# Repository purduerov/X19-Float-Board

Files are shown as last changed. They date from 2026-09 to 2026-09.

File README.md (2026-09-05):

# X19 Float Board

The Float Board manages buoyancy systems, motor drivers, sensor telemetry, and power distribution for the Purdue ROV X19 vehicle.

---

## 🚀 Quickstart: Opening the Project (Recommended)

**Always open the project using the 1-click launcher:**

* **Windows:** Double-click `LAUNCH_KICAD.bat`
* **macOS / Linux:** Run `./LAUNCH_KICAD.sh`

### What the Launcher Does Automatically:
1. ⚙️ **Configures Git Hooks & Clean Filters:** Sets up Git to strip volatile viewport/zoom coordinates on every commit, preventing merge conflicts.
2. 🔄 **Auto-Updates Component Library:** Pulls the freshest symbols, footprints, and 3D models from `purdue-rov-kicad-lib` before opening.
3. 📐 **Opens KiCad:** Launches `X19-Float-Board.kicad_pro` with all 6 central library categories pre-linked.

---

## Cloning the Repository
Clone recursively to ensure the central component library is initialized:
```bash
git clone --recursive https://github.com/purduerov/X19-Float-Board.git
cd X19-Float-Board
```

## Central Component Library & Manager GUI

The project links to the central `purdue-rov-kicad-lib` submodule mapped across 6 categories in `sym-lib-table` and `fp-lib-table`:
- `rov_passives`: Resistors, capacitors, inductors, crystals
- `rov_power`: Voltage regulators, buck/boost converters, MOSFETs, diodes
- `rov_logic`: MCUs, logic ICs, op-amps, drivers, level shifters
- `rov_connectors`: Power terminals, XT60, headers, USB, JST connectors
- `rov_sensors`: IMUs, temperature, pressure sensors
- `rov_mech`: Mounting holes, standoffs, test points

### Launching the Library Manager GUI
To browse parts, inspect footprints, edit properties, or add/delete components in the shared library:
- **Windows:** Double-click `libs\purdue-rov-kicad-lib\LIBRARY_MANAGER.bat`
- **macOS / Linux:** Run `./libs/purdue-rov-kicad-lib/LIBRARY_MANAGER.sh`

## Schematic Hierarchy

The schematic is organized across functional sub-sheets:
- `X19-Float-Board.kicad_sch`: Root top-level sheet.
- `pwr.kicad_sch`: Power regulation and distribution.
- `stm32.kicad_sch`: Main microcontroller circuit and programming interface.
- `Motor.kicad_sch`: Motor driver stages and control signals.
- `sensor.kicad_sch`: Environmental and diagnostic sensor telemetry.
- `rf.kicad_sch`: Wireless/radio transceiver circuitry.
- `switch.kicad_sch`: Power switching logic.

## Design Rules & Clearances

- High-voltage / high-current motor traces maintain isolation rules configured in `custom_rules.kicad_dru`.
- All symbols must adhere to central library guidelines.

## Automated CI/CD & DevOps Preflight Checks

All CI/CD automation and tooling are centralized in [`purduerov/pcb-devops`](https://github.com/purduerov/pcb-devops):
1. **Automated Git Clean Filters:** Configured automatically by `.githooks/pre-commit` to prevent viewport/zoom merge noise.
2. **KiCad Symbol Linting:** Validates mandatory fields (`MPN`, `Manufacturer`, `Category`, `DigiKey`, `Datasheet`, `Temp_Range`) on all library components.
3. **ERC & DRC Validation:** Executes Electrical and Design Rules Checks via KiBot in GitHub Actions.
4. **Artifact Generation:** Automatically exports Schematic PDFs, Board Layout PDFs, and Interactive HTML BOMs on every pull request.

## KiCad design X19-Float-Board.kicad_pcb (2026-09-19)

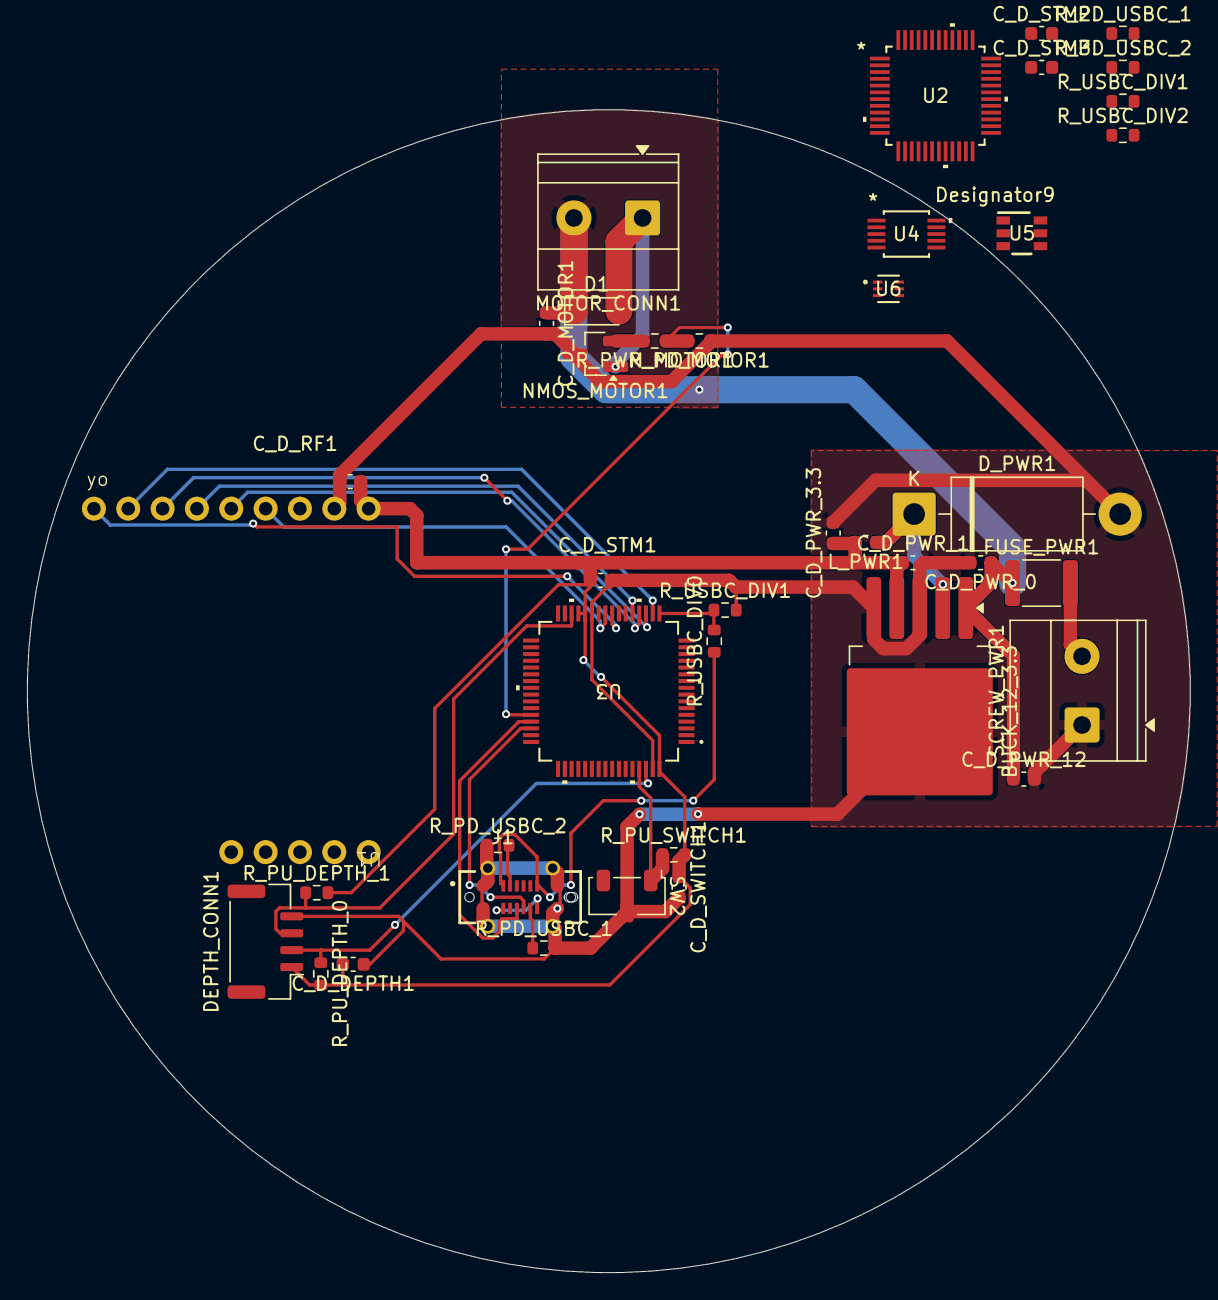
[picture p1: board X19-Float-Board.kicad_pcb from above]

Board: 2 copper layers, 86.0 x 86.0 mm, 41 parts (0 on the bottom side), 26 nets.

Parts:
BUCK_12_3.3: LM2596S-3.3; TO-263-5_TabPin3
C_D_DEPTH1: 100nF; C_0603_1608Metric
C_D_MOTOR1: 100nF; C_0603_1608Metric
C_D_PWR_0: 680µF; C_0603_1608Metric
C_D_PWR_1: 220µF; C_0603_1608Metric
C_D_PWR_3.3, C_D_PWR_12: 4.7µF; C_0603_1608Metric
C_D_RF1: 100nF; C_0603_1608Metric
C_D_STM1, C_D_STM2, C_D_STM3: 100nF; C_0603_1608Metric
C_D_SWITCH1: 100nF; C_0603_1608Metric
D1: D_MOTOR; D_SOD-123
DEPTH_CONN1: Conn_01x04_Pin; JST_GH_BM04B-GHS-TBT_1x04-1MP_P1.25mm_Vertical
D_PWR1: 1N5822; D_DO-201AD_P15.24mm_Horizontal
FUSE_PWR1: 2A 12V PTC fuse; Fuse_1812_4532Metric
J1: USB4220-03-1040-C_REVA; GCT_USB4220-03-1040-C_REVA
L_PWR1: 33µH; L_0603_1608Metric
MOTOR_CONN1: Motor; TerminalBlock_Phoenix_MKDS-1,5-2-5.08_1x02_P5.08mm_Horizont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
NMOS_MOTOR1: NMOS; SOT-23_Handsoldering
R_PD_MOTOR1: 10kΩ; R_0603_1608Metric
R_PD_USBC_1, R_PD_USBC_1#2: 5.1k; R_0603_1608Metric
R_PD_USBC_2, R_PD_USBC_2#2: 5.1kΩ; R_0603_1608Metric
R_PU_DEPTH_0, R_PU_DEPTH_1: 4.7kΩ; R_0603_1608Metric
R_PU_SWITCH1: 10kΩ; R_0603_1608Metric
R_PWM_MOTOR1: 220Ω; R_0603_1608Metric
R_USBC_DIV0, R_USBC_DIV1: 20kΩ; R_0603_1608Metric
R_USBC_DIV1#2, R_USBC_DIV2: 10kΩ; R_0603_1608Metric
SCREW_PWR1: Screw_Terminal_01x02; TerminalBlock_Phoenix_MKDS-1,5-2-5.08_1x02_P5.08mm_Horizont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
SW2: SW_Nidec_CAS-120A1; Nidec_Copal_CAS-120A
U1: rf module
U2: STM32C542CCT6; LQFP48-7X7
U3: STM32G431RBT6; LQFP64-10x10mm
U4: INA228AIDGSR; VSSOP10_DGS_TEX
U5: TPS561208DDCR; DDC0006A_N
U6: TMP1075NDRLR; SOT5X3-6_DRL_TEX

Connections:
3.3 V: BUCK_12_3.3.4 (FB), C_D_DEPTH1.2, C_D_PWR_1.1, C_D_PWR_3.3.1, C_D_RF1.2, C_D_STM1.1, C_D_STM2.2, C_D_STM3.1, C_D_SWITCH1.1, DEPTH_CONN1.1, L_PWR1.2, R_PU_DEPTH_0.2, R_PU_DEPTH_1.2, R_PU_SWITCH1.2, U1.6 (VIN), U2.9 (VREF+), U2.24 (VDD), U2.48 (VDD), U3.28 (VREF+), U3.29 (VDDA), U3.64 (VDD), U4.6 (VS), U6.5 (V+)
12 V: BUCK_12_3.3.1 (VIN), C_D_MOTOR1.1, C_D_PWR_0.1, C_D_PWR_12.1, D1.1 (K), FUSE_PWR1.1, MOTOR_CONN1.2, U5.3 (VIN)
/Motor/Motor PWM: R_PD_MOTOR1.2, R_PWM_MOTOR1.1, U2.19 (PB1), U3.44 (PA10)
/Sensors/Depth SCL: DEPTH_CONN1.2, R_PU_DEPTH_0.1, U2.39 (PB3)
/Sensors/Depth SDA: DEPTH_CONN1.3, R_PU_DEPTH_1.1, U2.40 (PB4)
/Switch/switch: R_PU_SWITCH1.1, SW2.1 (C), U2.38 (PA15), U3.61 (PB8-BOOT0)
/USB-C/USB-C_VBUS_A: R_USBC_DIV1.2, R_USBC_DIV2.1
/rf/RF INT: U1.9 (G0), U2.18 (PB0), U3.25 (PB1)
/rf/RF MISO: U1.11 (MISO), U2.16 (PA6), U3.21 (PA7)
/rf/RF MOSI: U1.12 (MOSI), U2.15 (PA5), U3.20 (PA6)
/rf/RF NSS: U1.13 (CS), U2.13 (PA3), U3.18 (PA4)
/rf/RF RST: U1.14 (RST), U2.17 (PA7), U3.24 (PB0)
/rf/RF SCK: U1.10 (SCK), U2.14 (PA4), U3.19 (PA5)
GND: BUCK_12_3.3.3 (GND), BUCK_12_3.3.5 (~ON/OFF), C_D_DEPTH1.1, C_D_MOTOR1.2, C_D_PWR_0.2, C_D_PWR_1.2, C_D_PWR_3.3.2, C_D_PWR_12.2, C_D_RF1.1, C_D_STM1.2, C_D_STM2.1, C_D_STM3.2, C_D_SWITCH1.2, DEPTH_CONN1.4, D_PWR1.2 (A), J1.A1 (GND_A), J1.A12 (GND_A), J1.B1 (GND_B), J1.B12 (GND_A), J1.S1 (SHIELD), J1.S2 (SHIELD), J1.S3 (SHIELD), J1.S4 (SHIELD), NMOS_MOTOR1.3 (S), R_PD_MOTOR1.1, R_PD_USBC_1.2, R_PD_USBC_1#2.2, R_PD_USBC_2.1, R_PD_USBC_2#2.1, R_USBC_DIV1#2.2, R_USBC_DIV2.2, SCREW_PWR1.1, SW2.2 (B), U1.7 (GND), U2.23 (VSS), U2.47 (VSS), U3.27 (VSSA), U3.63 (VSS), U4.1 (A1), U4.2 (A0), U4.7 (GND), U5.1 (GND), U6.2 (GND), U6.4 (A0)
unnamed: BUCK_12_3.3.2 (OUT), D_PWR1.1 (K), L_PWR1.1
unnamed: D1.2 (A), MOTOR_CONN1.1, NMOS_MOTOR1.1 (D)
unnamed: J1.A5 (CC1), R_PD_USBC_2.2, R_PD_USBC_2#2.2
unnamed: J1.B5 (CC2), R_PD_USBC_1.1, R_PD_USBC_1#2.1
unnamed: J1.B7 (DN2), U3.45 (PA11)
unnamed: J1.B6 (DP2), U3.46 (PA12)
unnamed: NMOS_MOTOR1.2 (G), R_PWM_MOTOR1.2
unnamed: FUSE_PWR1.2, SCREW_PWR1.2
unnamed: R_USBC_DIV0.2, R_USBC_DIV1#2.1, U3.17 (PA3)
unnamed: U4.8 (VBUS), U4.10 (IN+)
VBUS_A: J1.A4 (VBUS_A), J1.A9 (VBUS_A), R_USBC_DIV0.1, R_USBC_DIV1.1
VBUS_B: J1.B4 (VBUS_B), J1.B9 (VBUS_B)

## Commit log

2026-07-24 chore: initialize project name to X19-Float-Board and cleanup template config
    [X19-Float-Board.kicad_pcb, X19-Float-Board.kicad_sch]
2026-07-24 Draft of Schematic
    I just pasted in my old draft so it's on the repository
    [X19-Float-Board.kicad_sch]
2026-07-27 Added hierarchical sheets
    Added the sheets and how I'm splitting up the components, may have used too many, I'm not sure how to use these. Will update components and wiring soon
    [Motor.kicad_sch, X19-Float-Board.kicad_sch, rf.kicad_sch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]
2026-07-28 Overhaul
    Overhauled the schematic so all the components are correct, rewired power to be 12 V instead of 9 V and connected hierarchical labels between modules. Added more decoupling capacitors where they were missing.
    [Motor.kicad_sch, X19-Float-Board.kicad_sch, pwr.kicad_sch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]
2026-07-28 Clean up
    Minor fixes to mistakes in the schematic
    [Motor.kicad_sch, pwr.kicad_sch, rf.kicad_sch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]
2026-07-29 started layout
    in meeting
    [X19-Float-Board.kicad_pcb, sensor.kicad_sch, untitled.kicad_sch]
2026-08-12 Footprint
    Found footprints for multiple components and imported them to be used in PCB
    [X19-Float-Board.kicad_pcb, rfimp.kicad_pcb, rfimp.kicad_sch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]
2026-08-12 Gave footprints to everything
    Footprints
    [Motor.kicad_sch, X19-Float-Board.kicad_sch, pwr.kicad_sch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]
2026-08-13 Custom RF module and component
    Created my own setup for the footprint for the custom RF module
    [X19-Float-Board.kicad_pcb, rf.kicad_sch]
2026-08-13 Corrected stm32 symbol
    made corrections to the stm32 for the package and the schmeatic
    [X19-Float-Board.kicad_pcb, stm32.kicad_sch]
2026-08-14 ci(devops): setup centralized hardware CI/CD pipeline and PDF autogeneration for schematic and layout
2026-08-19 Modifications to power system to support what is required
    modified
    [X19-Float-Board.kicad_pcb, X19-Float-Board.kicad_sch, pwr.kicad_sch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]
2026-08-19 Completed routing of PCB
    Placed all components and routed pcb, large amount of drc errors, unsure
    [X19-Float-Board.kicad_pcb]
2026-08-19 Finalized Traces
    Potentially finallized traces
    [X19-Float-Board.kicad_pcb]
2026-08-19 Schematic updates
    Schematic updates to match with pcb edits
    [pwr.kicad_sch]
2026-08-27 docs: rewrite README with board-specific documentation and update submodule
2026-08-27 chore(submodule): update purdue-rov-kicad-lib to latest master
2026-09-01 refactor: organize scripts into scripts/ directory and configure 6-category library tables and launchers
    [untitled.kicad_sch]
2026-09-01 refactor: eliminate local scripts and centralize all automation in pcb-devops
2026-09-01 chore(ci): update pinned pcb-devops SHA and reflect PDF/BOM outputs in docs
2026-09-01 feat(ci): enable automated GitHub Pages portal and live interactive BOM deployment
2026-09-01 ci: point reusable workflow to pcb-devops@master for zero-maintenance CI propagation
2026-09-01 feat: auto-pull latest board commits with autostash on project launch
2026-09-02 refactor(launcher): proxy root LAUNCH_KICAD scripts directly to central pcb-devops master
2026-09-02 USB-C + Complete wiring
    Compltetly wired the pcb (I don't understand the DRC errors) and added a usb C to flash the stm, modified the switch to be the BOOT0 for the stm so it controls whether the stm is in flash mode
    [Motor.kicad_sch, X19-Float-Board.kicad_pcb, X19-Float-Board.kicad_sch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]
2026-09-05 Checkpoint
    Checkpoint, pre battery telemetry, pre new stm
    [Motor.kicad_sch, X19-Float-Board.kicad_pcb, sensor.kicad_sch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]
2026-09-05 Library Reforms
    moved libraries around
    [rfimp.kicad_pcb, rfimp.kicad_sch]
2026-09-05 Updated components from x19 BOM
    components
2026-09-09 chore: remove tracked backup file X19-Float-Board-eagle-import.bak
2026-09-09 chore(submodule): ensure purdue-rov-kicad-lib points to latest master
2026-09-09 chore(submodule): sync purdue-rov-kicad-lib to 3b036a0
2026-09-09 chore(submodule): sync purdue-rov-kicad-lib to b8f2bd1
2026-09-09 chore(infra): sync goated KiCad launcher, library tables, and purdue-rov-kicad-lib
2026-09-10 chore(githooks): harden submodule sync and update purdue-rov-kicad-lib
2026-09-10 chore(submodule): update purdue-rov-kicad-lib to d63fa5e
2026-09-10 chore(infra): sync latest infrastructure tooling from board-template
2026-09-10 chore(submodule): sync purdue-rov-kicad-lib to latest master
2026-09-19 Update
    Update
    [TELEM.kicad_sch, USB-C.kicad_sch, X19-Float-Board.kicad_pcb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]
2026-09-19 chore(submodule): fast-forward purdue-rov-kicad-lib to latest master
2026-09-19 Small changes to hierarchy
    Small Changes
    [X19-Float-Board.kicad_sch]
2026-09-19 todolist update
    update of the to do list on schematic
    [USB-C.kicad_sch, X19-Float-Board.kicad_pcb, X19-Float-Board.kicad_sch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]
2026-09-19 chore(submodule): bump purdue-rov-kicad-lib to latest master
2026-09-19 ci: set strict_drc to false to generate PDFs and artifacts for WIP boards
2026-09-21 Updated Schematic
    Updated parts of todo list for schematic
    [TELEM.kicad_sch, X19-Float-Board.kicad_sch, pwr.kicad_sch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]
2026-09-22 Updated Schematic
    Updated schematic
    Cleaned up dense portions
    added H bridge
    correct i2c wiring
    added ferrite beads
    added 12 V power monitoring
    added stlink
    added power mux
    added power from usb
    reformatted hierarichal sheets
    [Motor.kicad_sch, TELEM.kicad_sch, X19-Float-Board.kicad_sch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]
2026-09-24 chore(submodule): auto-update purdue-rov-kicad-lib to latest master
2026-09-26 feat: adopt ROV PCB platform contract
2026-09-26 ci: grant the reusable update workflow least-privilege permissions
    A reusable workflow can only narrow the caller's token, never widen it, so this
    wrapper has to declare what the called workflow asks for. Without its own
    permissions block the call is clamped to the repository default, which is
    read-only on several boards, and every scheduled library update fails to push
    the update branch or open its pull request while still looking green. The five
    documented inputs are unchanged.
2026-09-26 chore: ignore KiCad project backup archives
2026-10-03 USB, TVS, LDO, Passives, I2C
    applied changes to usb circuitry, tvs, ldo, passibes and i2c.
    [Motor.kicad_sch, TELEM.kicad_sch, USB-C.kicad_sch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]
2026-10-07 float
    float for claude review
    [Motor.kicad_sch, TELEM.kicad_sch, pwr.kicad_sch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]
2026-10-12 chore(library): update purdue-rov-kicad-lib submodule
2026-10-24 footprints
    footprints
2026-10-31 Finished footprints
